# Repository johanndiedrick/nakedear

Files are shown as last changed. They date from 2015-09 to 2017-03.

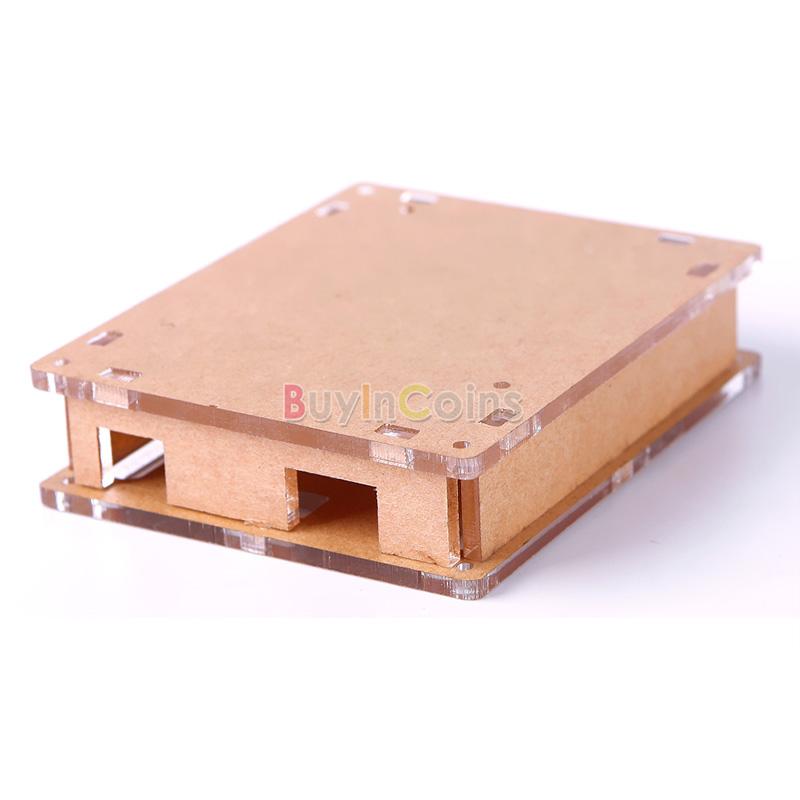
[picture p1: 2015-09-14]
materials/boxes/references/069354-1-02.jpg

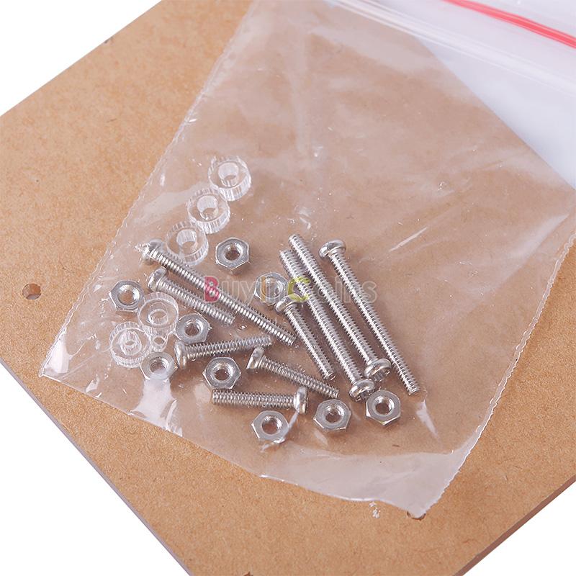
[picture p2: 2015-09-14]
materials/boxes/references/069354-1-06.jpg

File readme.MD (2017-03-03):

# Naked Ear
## Introduction to Tools and Techniques for Sound Art

### Description

This workshop is for artists and researchers wanting to become more
familiar with the potential of sound. Our focus will be on expanding our
understanding of sound in an environment. This requires a basic vocabulary
for talking about sound as a material, as well as the ability to make and
use tools for investigating and manipulating sound for creative purposes.

Our frame of reference will be Good Vibrations, a mobile listening kit that
allows "acoustic explorers" to find the lesser audible soun=
ds in their
environment. By using hand- made microphones and amplifiers, listeners can
tune into the subtle vibrations

that usually go unnoticed. The project encourages listeners to reimagine
their sonic environment by playfully exploring the world through their ears.

The workshop will introduce participants to the world of sound art, while
providing techniques for making tools for creating these experiences. This
will include

the fabrication of hand-made microphones, speakers, and amplifiers for use
in installations, performances, and scientific research. The goal of the
workshop is

to take these tools into the field and use them for artistic investigation
and public engagement.

### Content

For the first session, students will be introduced to the sound art
practice. Examples of seminal and canonical works will be presented, giving
students a taste of potential projects. From there we will move onto
describing the basic physics and properties of sound. Our introduction will
end with an explanation of how sound is received through a microphone,
amplified with an amplifier, and sent through a speaker to produce audible
sound.

The rest of the workshop will consist of building a contact microphone, a
speaker and an amplifier. From there we will take our tools out into nearby
McCarren Park and amplify found sounds.

### Outline

**Session 1**

-  Hour 1: Introductions

- Overview of sound art

- Overview of physics of sound

- Overview of how micrphone, speaker, and amplifier work

-  Hour 2: Microphone

- Contact microphone build

- https://www.youtube.com/watch?v=P8iAshJ1Pk0

- https://www.youtube.com/watch?v=yz5CM0eCGA0

-  Hour 3: Speaker

- Speaker build

-  Hour 4: Amplifier

- Amplifier build on breadboard

**Session 2**

- Hour 1:

- Amplifier build on PCB

- Hour 2:

- Placing amplifier in enclosure

- Hour 3:

- Exploring McCarren Park with listening kits

- Hour 4:

- Presentation of experiments

## Student Profile

Students do not need to have any electronic experience. Some soldering
experience is a plus but is not required. An expertise knowledge of sound
and how it works is also not required. A large part of the workshop is to
teach that to you! A strong curiosity and willingness to learn about sound
is the only basic requirement.

## What students get from your profile; software, materials to work

- One contact mic

- One speaker

- One amplifier

- One custom enclosure with custom pcb

- Reference material (excerpts from Electronic Music Handbook, David Dunn's
microphone PDF etc.)

## Pre requisites and preparation for the workshop

Things we will need in the studio for each student:

- Soldering station

- Solder

- Multimeter

- Wire

- Jumper wires

## Instructor short bio

Johann Diedrick makes installations, performances, and software that allow
people to activly participate in the production of sound. His work has been
exhibited internationally in numerous group exhibitions, conferences and
festivals, including the New Interfaces for Musical Expression (NIME)
conference in Daejeon and Seoul, Korea, the Invisible Places, Sounding
Cities conference in Viseu, Portugal, and the Dumbo Arts Festival in
Brooklyn, New York. He received his Masters in Professional Studies at the
Interactive Telecommunications Program (ITP) at Tisch School of the Arts at
New York University, focusing on sound art. During time at ITP he was a
researcher at the InterLab at the Yamaguchi Center for Arts and Media
(YCAM) in Yamaguchi, Japan. Afterwards he worked as an interactive software
developer at Qosmo in Tokyo, Japan. He is currently a software developer at
the Metropolitan Museum of Art.

## Instructor Links, website, social media

Website: http://www.johanndiedrick.com

Github: @jdiedrick

Twitter: @jdiedrick

Instagram: @johanndiedrick

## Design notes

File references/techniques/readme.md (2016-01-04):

# References

## Public Installations

[Soundaffects](http://www.creativeapplications.net/maxmsp/soundaffects-maxmsp-sound-arduino/)

[Sum of Days](http://www.moma.org/calendar/exhibitions/1151?locale=en)

##  Transmitting FM

[TRANSMITTING FM, AM, SSB, SSTV AND FSQ WITH JUST A RASPBERRY PI](http://www.rtl-sdr.com/transmitting-fm-am-ssb-sstv-and-fsq-with-just-a-raspberry-pi/)

## Acoustic Ecology

[American Society for Acoustic Ecology](http://acousticecology.us/about/)

## VLF

[VLF Radio Project](http://www.aurora-service.eu/vlf-radio-project/)

[Auroral Chorus](https://archive.org/details/AuroralChorusIiiTheMusicOfTheMagnetosphere-Disc2Of2)

## Ultrasonic (bat detectors!)

[Build a Simple Bat Detector](http://pw1.netcom.com/~t-rex/BatDetector.html)

[Bat Detector](http://www.njsas.org/projects/bat_detector/index.html)

## DIY Microphones

[Rolling Your Own Microphones](http://traktoria.org/files/sonar/Microphones_Hydrophones_Vibration-Transducers__Rolling_Your_Own__Dunn2007.pdf)

## Sine-wave speech

[Diana Deutsch' Speech to Song](http://deutsch.ucsd.edu/psychology/pages.php?i=212)

[Sine-wave speech](http://www.mrc-cbu.cam.ac.uk/people/matt-davis/sine-wave-speech/)

## Shepard Tone

[Shepard Tone](https://www.youtube.com/watch?v=BzNzgsAE4F0)

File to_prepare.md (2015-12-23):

x number of soldering stations
x number of wire strippers
Flux
x number of materials bags, enclosues, pcbs etc.
Tape
Plastic dip
Projector
Documentation - hire photographer or ask Reverse if interns will document?

longer ai/ao
acryllic
screws/longer top
4 soldering iron stations
3" screws + washers
speakers
day 1 prep
plastic bags
mini screwdriver

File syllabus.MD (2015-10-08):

# Naked Ear

**_Day 1_**

## Section One: Overview

Listening Exercise: Tristan Perich's One Bit Symphony 
Viv Corringham

Introductions

	- Name, where are you from, favorite dessert

Rules for Basic Human Decency

	- Borrow from Jer Thorp/Punk poster

Why are we all here? 

Why am I here? Because this is what I do and I wan to teach peolpe about my passion! (...)

- Introduce Good Vibrations here? I want to get their hands on it early...

Go over outline of course

- some lecture, lots of (listening) examples, mostly building and making, doing and exploring, talking and listening

### What is Sound Art?

#### Carve out definition through examples

- Sculpture

	..* _Homage to New York_, Jean Tinguely, 1960 - [MoMA Collection Page](http://www.moma.org/collection/works/81174) | [YouTube](https://www.youtube.com/watch?v=0MqsWqBX4wQ)

- Installation

	..* _Transfinite_, Ryoji Ikeda, 2011 - [Artist's website'(http://www.ryojiikeda.com/project/thetransfinite/) | [YouTube](https://www.youtube.com/watch?v=omDK2Cm2mwo)

- Environment

	..* _Times Square_, Max Neuhaus

-. Performances

	..* _Hair Hymn_, A Pure Apparatus (Xuan Ye), 2014-2015 - [Artist's website](http://a.pureapparat.us/hair-hymn/)

- Architecture

	..* Estonia forest project 

- . Something in between

	..* _viewKoma_, Tetsuya Umeda and Kanta Horio, 2006 - [YouTube](https://www.youtube.com/watch?v=42MLNXqMGzA)

#### Formal definition?

	- Look in a book

### What is sound?

Without thinking about the "art", lets examine the sound in sound art

A bit of a physics lesson...

Sound is vibration

- Vibration can be described as waves

- Show what waves are, with simple description of features (wavelength, amplititude)

Sound is vibration perceived by our ears

	- Audio-vision: earliest sense
	- Seth Horowitz, vibration being one of the first external stimuli organisms experienced

	- Explain how this translates to sound (Frequency, Intensity (vs. Loudness/Volume) )

Sound is perceived vibration by our ears within a certain range

- Show diagram of human hearing range 

- Show range of volume

Why think about sound? Why is sound important?

Sound is everywhere, literally.

The absense of sound is almost impossible

	- John Cage's Silence
	
	- Anechoic Chamber

It affects our psychology

	- Look at noise psychology studies

It affects our environment

	- Whales and noise pollution underground
	
	- Sound as indicator of biodiversity

In an arts pratice, its ripe for explorating and expression, very much overlooked and can be a powerful tool when used thoughtfully.

	- Janet Cardiff: Her Long Black Hair, 40 Part Motet, Murder of Crowes

So within all of this, what are we talking about today? What are we going to be looking at? Making?

A basic sound system with one input, one output, and a mediator in between

We're going to look at small sounds, and how we can amplify them for listening pleasure, artstic expression, and scientific investigation

Introduce Good Vibrations

Pass around and show everyone what we will be making

Explain 3 main parts, and transition into the first part we are going to focus on making

"One part is already done (headphones)! Just two parts to make"

## Section Two: Microphones

Play sound sample: Night Passages 

Explain how microphones work

In general, microphones take in vibration and translate it into a signal. How that is used depends on the application. For our purposes, we will say the microphone moves or gets excited due to vibration, converts its own vibration into an electrical signal, and recreates that signal at the other end through speakers or headphones

The microphone doesn't do all of this, but it is the input for this application.

Explain different kinds of microphones work

- Dynamic

- Condenser

- Shotgun

- Directional

- Ultrasonic: Eisuke

- Hydrophonic

- Boundary

- Binaural microphones

[David Dunn's Rolling Your Own Microphones](http://traktoria.org/files/sonar/Microphones_Hydrophones_Vibration-Transducers__Rolling_Your_Own__Dunn2007.pdf)

[Micro Listening Workshops](http://subtropics.org/micro-listening-workshops/)

We're going to look at piezo microphone, for surface vibrations. Wildly powerful, inexpensive, easy to use for a variety of applications.

Explain parts of microphone

1) Piezo

2) Audio cable

3) Standard audio jack

4) A little flair

Begin to assemble microphone

Cut wire to arms span length

Quick introduction to soldering!

- Solder pizeo

- Keep track of power vs ground

- Solder 1/4" jack, keeping in mind

- Look at Nick Collin's videos for soldering and pizeo prep references

- Plasti dip ends and wait to dry!

## Section Three: Speakers

	- Inverse of microphone

	- Explain briefly, explain that we won't be building one

## Section Four: Amplifiers

Listening exercise: VLF recordings? David Dunn's beatle recordings

Explain that while we have a microphone we need to make it a little louder for us to hear those small sounds!

So we're going to build an amplifier, a pretty basic one:

	- Diagram of circuit we are going to build

		- Ask if anyone has seen a circuit diagram before
	
	- Explain a bit what the circuit does/how it works

	- Build circuit together

		- Explain breadboard

	- Test out circuit so they know what they have built, and prepare them for tomorrow

**_Day 2_** 

Listening exercise: APA and jø - Cloudbursting

### Section Five: Assembling Part 1: Amplifier

Explain reasoning: 

	- Makes it more secure

	- Why didn't we just start with this? Makes us iterate again, for learning and practice

- Assemble PCB with parts from yesterday

### Section Six: Assembling Part 2: Enclosure

Listening exercise: TBD

- Assemble Enclosure and finish mobile listening kits!

### Section Seven: Exploring

Listening exercise: McCarren Park

- Do mobile lisening exercise in McCarren Park, prepare cards for prompts

### Section Eight: Presenting

Listening exercise: the world!

 - Come up with prompts for discussion

 - Ask for feedback for the course!

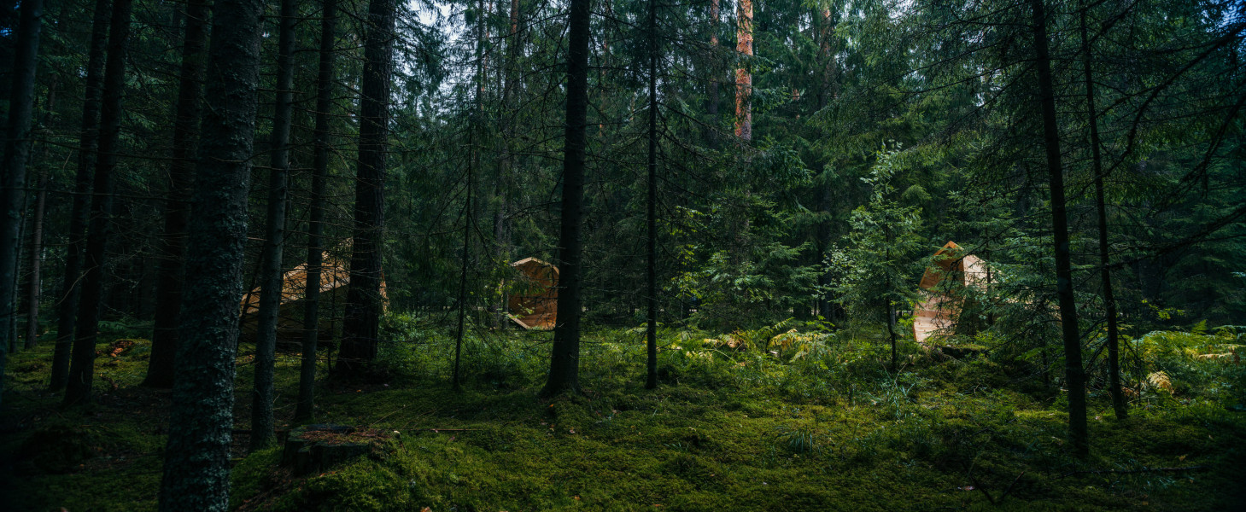
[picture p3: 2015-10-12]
presentation/img/estonia1.jpg

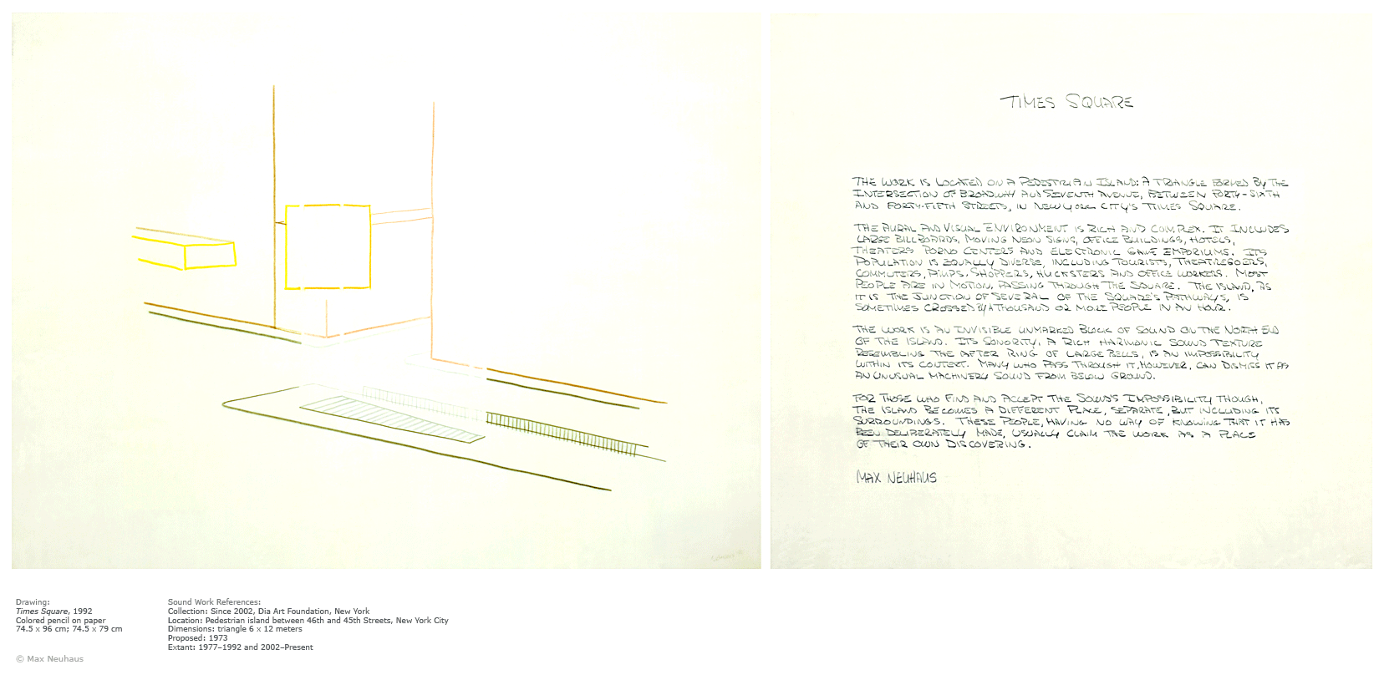
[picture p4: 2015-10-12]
presentation/img/TimesSquare.gif

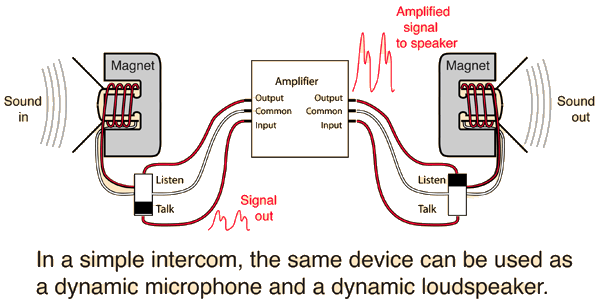
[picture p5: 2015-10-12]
presentation/img/amplifier.gif

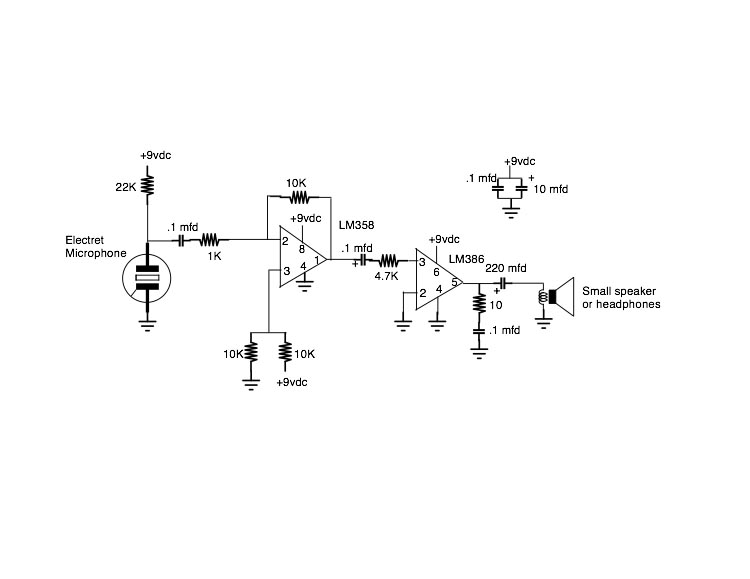
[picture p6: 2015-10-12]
presentation/img/amplifiercircuit.jpg

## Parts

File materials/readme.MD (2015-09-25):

# Materials List

## From Jameco

- [Breadboard](https://www.jameco.com/webapp/wcs/stores/servlet/ProductDisplay?productId=20601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)

- [9V Battery Clip](https://www.jameco.com/webapp/wcs/stores/servlet/ProductDisplay?productId=11280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)

- [10K Potentiometer](https://www.jameco.com/webapp/wcs/stores/servlet/ProductDisplay?productId=29082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)

- [1/4" Shaft Knob](https://www.jameco.com/webapp/wcs/stores/servlet/ProductDisplay?productId=264990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)

- [Toggle Switch](https://www.jameco.com/webapp/wcs/stores/servlet/ProductDisplay?productId=76523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)

- [220 uf Capacitor](https://www.jameco.com/webapp/wcs/stores/servlet/ProductDisplay?productId=158263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)

- [Mono Phone Jack](https://www.jameco.com/webapp/wcs/stores/servlet/ProductDisplay?productId=2100291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)

- [Stereo Phone Jack](https://www.jameco.com/webapp/wcs/stores/servlet/ProductDisplay?productId=568392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)

- [Mono Phone Plug](https://www.jameco.com/webapp/wcs/stores/servlet/ProductDisplay?productId=231160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)

- [LM386](https://www.jameco.com/webapp/wcs/stores/servlet/ProductDisplay?productId=24125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)

- [LM358](https://www.jameco.com/webapp/wcs/stores/servlet/ProductDisplay?productId=826793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)

- [Heat Shrink](https://www.jameco.com/webapp/wcs/stores/servlet/ProductDisplay?productId=2095963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)

## From Digikey

- [Piezo Elements](http://www.digikey.com/scripts/DkSearch/dksus.dll?Detail&itemSeq=180563742&uq=635787224790071919)

## From Amazon

- [Plasti Dip](http://www.amazon.com/gp/product/B00I9SK8XY/ref=ox_sc_imb_mini_detail?ie=UTF8&psc=1&smid=ATVPDKIKX0DER)

- [Pipe Cleaners](http://www.amazon.com/gp/product/B000GAZ4NC/ref=ox_sc_imb_mini_detail?ie=UTF8&psc=1&smid=ATVPDKIKX0DER)

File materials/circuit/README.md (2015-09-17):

Based on this circuit:

http://www.basicanalogcircuits.com/Session_8.html

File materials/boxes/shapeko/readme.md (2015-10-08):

http://easel.inventables.com/

notes

say materials thicker
zero z closer
holes arent big enough
needs holder for mic
slits for strap
no tabs, cut outside line
cut circles first
double depth intervals

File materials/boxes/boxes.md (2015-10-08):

http://www.ebay.com/itm/Enclosure-Transparent-Acrylic-Box-Case-for-Arduino-Uno-R3-board-R3-DIY-Useful/231496186225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

http://www.ebay.com/itm/Enclosure-Transparent-Acrylic-Box-Case-for-Arduino-Uno-R3-board-R3-/261835213419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

http://7hillsmake.org/2012/03/16/making-laser-cut-acrylic-boxesenclosures/

http://comingsoon.radioshack.com/project-enclosure-8x6x3-/2701809.html

https://www.youtube.com/watch?v=uao-sinxbBs

http://www.makercase.com/

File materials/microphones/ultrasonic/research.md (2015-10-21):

ultrasonic microphone research
http://sound.stackexchange.com/questions/2359/re-recording-ultrasonic-frequencies
http://www.wildlife-sound.org/equipment/technote/micdesigns/index.html
http://www.wildlife-sound.org/equipment/technote/micdesigns/ultrasonic.html
Knowles Acoustics FG-3329 electret condenser microphone
david dunn's manual

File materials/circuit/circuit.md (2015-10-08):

`http://www.basicanalogcircuits.com/Session_8.html`

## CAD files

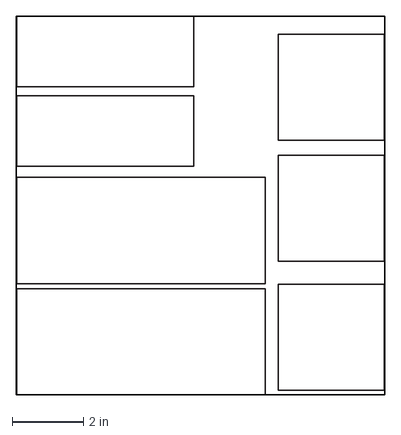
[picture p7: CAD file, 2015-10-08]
materials/boxes/designs/box_test.dxf
10.4 x 10.7 in

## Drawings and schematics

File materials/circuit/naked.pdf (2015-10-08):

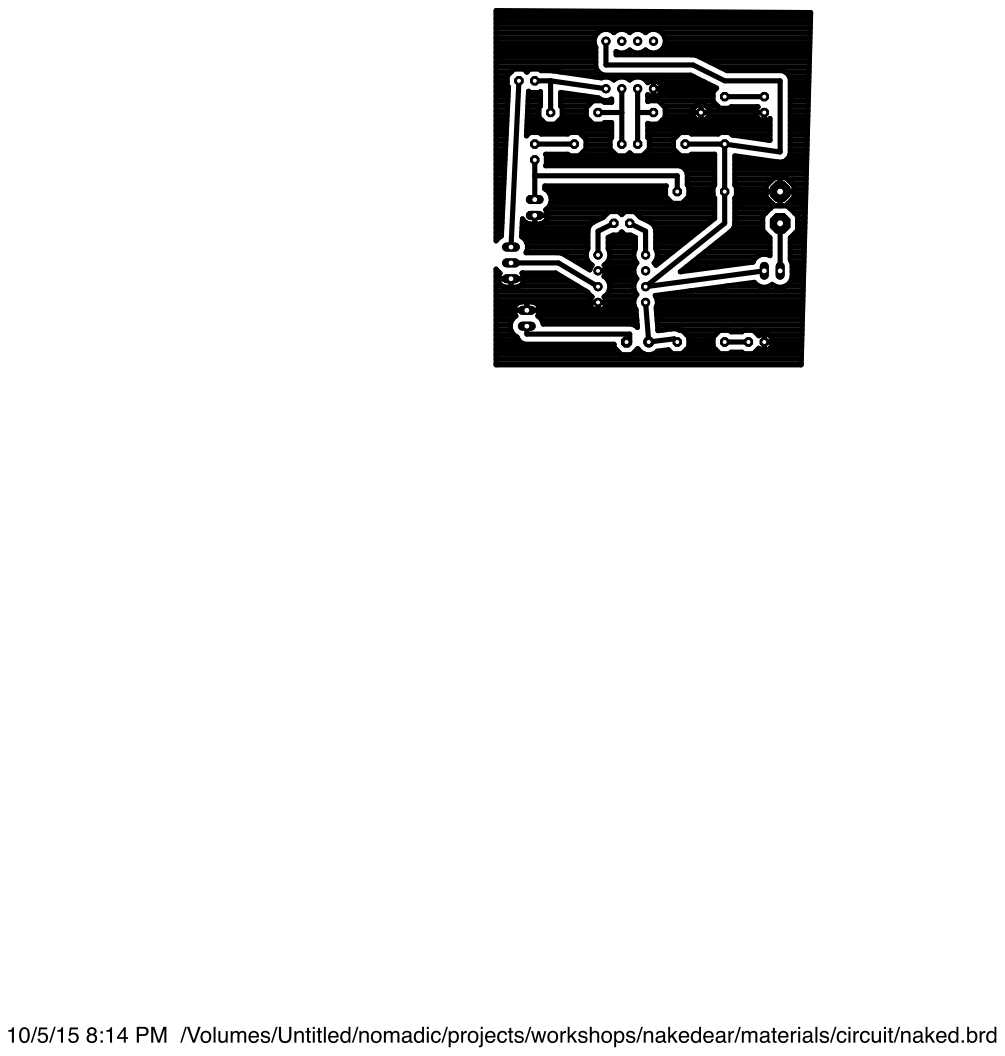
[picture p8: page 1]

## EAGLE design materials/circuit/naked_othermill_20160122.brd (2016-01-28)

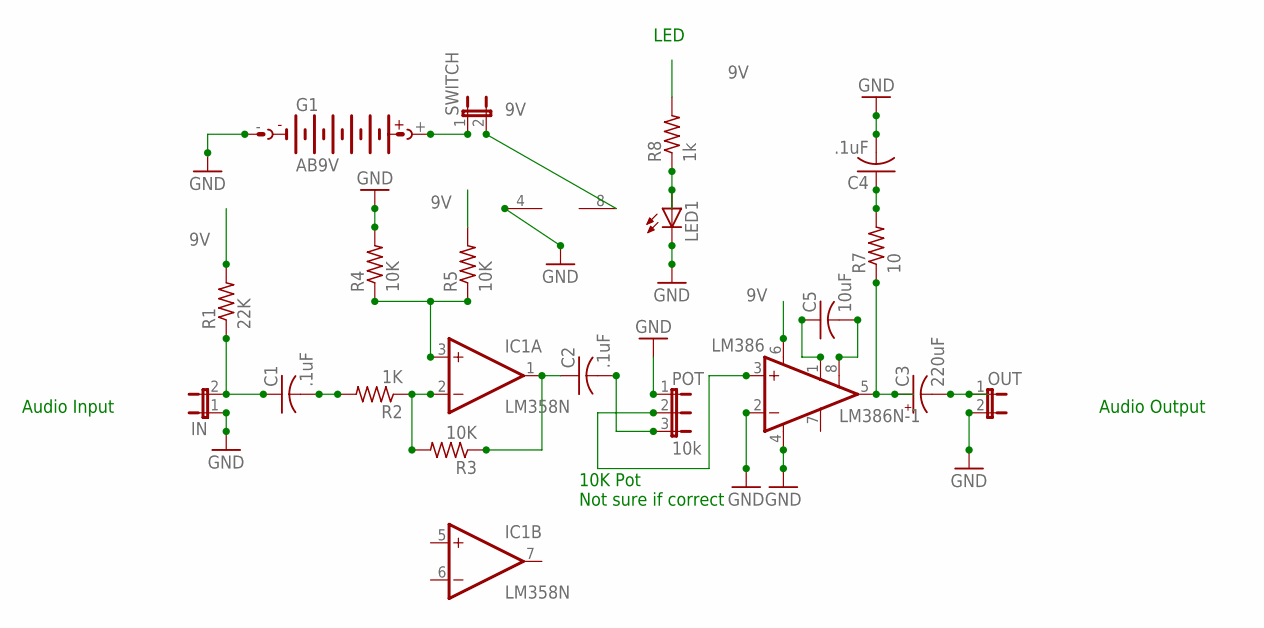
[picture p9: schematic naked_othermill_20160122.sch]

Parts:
C1, C2, C4: .1uF; C025-024X044
C3: 220uF; E3,5-8
C5: 10uF; C025-024X044
G1: AB9V
IC1: LM358N; DIL08
IN: JP1E; JP1
LED1: LED5MM
LM386: LM386N-1; DIL08
OUT: JP1E; JP1
POT: 10k; JP2
R1: 22K; 0204/7
R2: 1K; 0204/7
R3, R4, R5: 10K; 0204/7
R7: 10; 0204/7
R8: 1k; 0204/7
SWITCH: JP1E; JP1

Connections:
9V: IC1.8 (V+), LM386.6 (VS), R1.2, R5.2, R8.2, SWITCH.2
GND: C4.2, G1.-, IC1.4 (V-), IN.1, LED1.K (C), LM386.2 (-IN), LM386.4 (GND), OUT.2, POT.1, R4.2
unnamed: G1.+, SWITCH.1
unnamed: C1.1, IN.2, R1.1
unnamed: C1.2, R2.2
unnamed: IC1.2 (-IN), R2.1, R3.2
unnamed: C5.1, LM386.1 (GAIN)
unnamed: IC1.3 (+IN), R4.1, R5.1
unnamed: C2.1, IC1.1 (OUT), R3.1
unnamed: C2.2, POT.3
unnamed: LM386.3 (+IN), POT.2
unnamed: C3.+, LM386.5 (OUT), R7.1
unnamed: C3.-, OUT.1
unnamed: LED1.A, R8.1
unnamed: C4.1, R7.2
unnamed: C5.2, LM386.8 (GAIN)

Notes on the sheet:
Audio Input
Audio Output
LED
10K Pot Not sure if correct

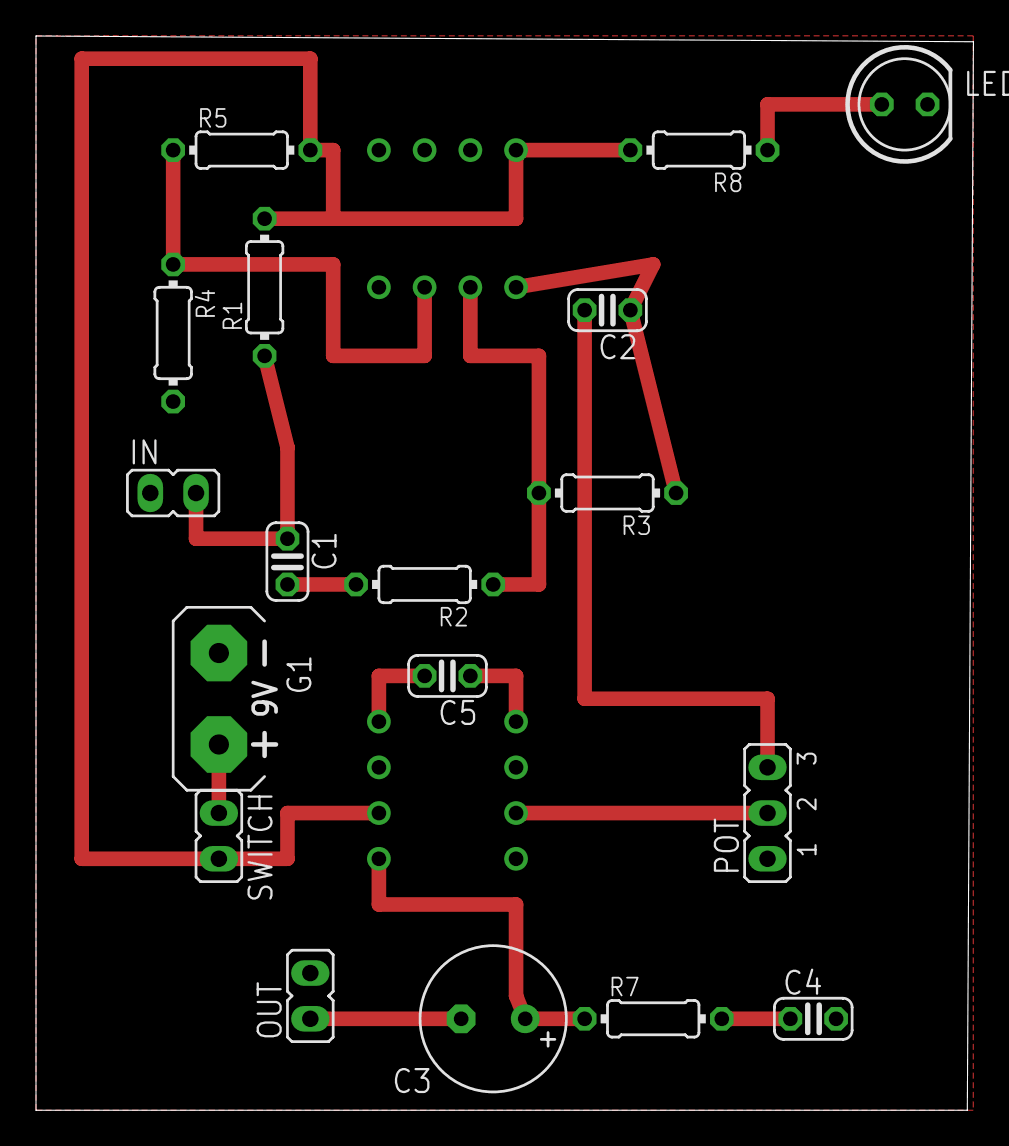
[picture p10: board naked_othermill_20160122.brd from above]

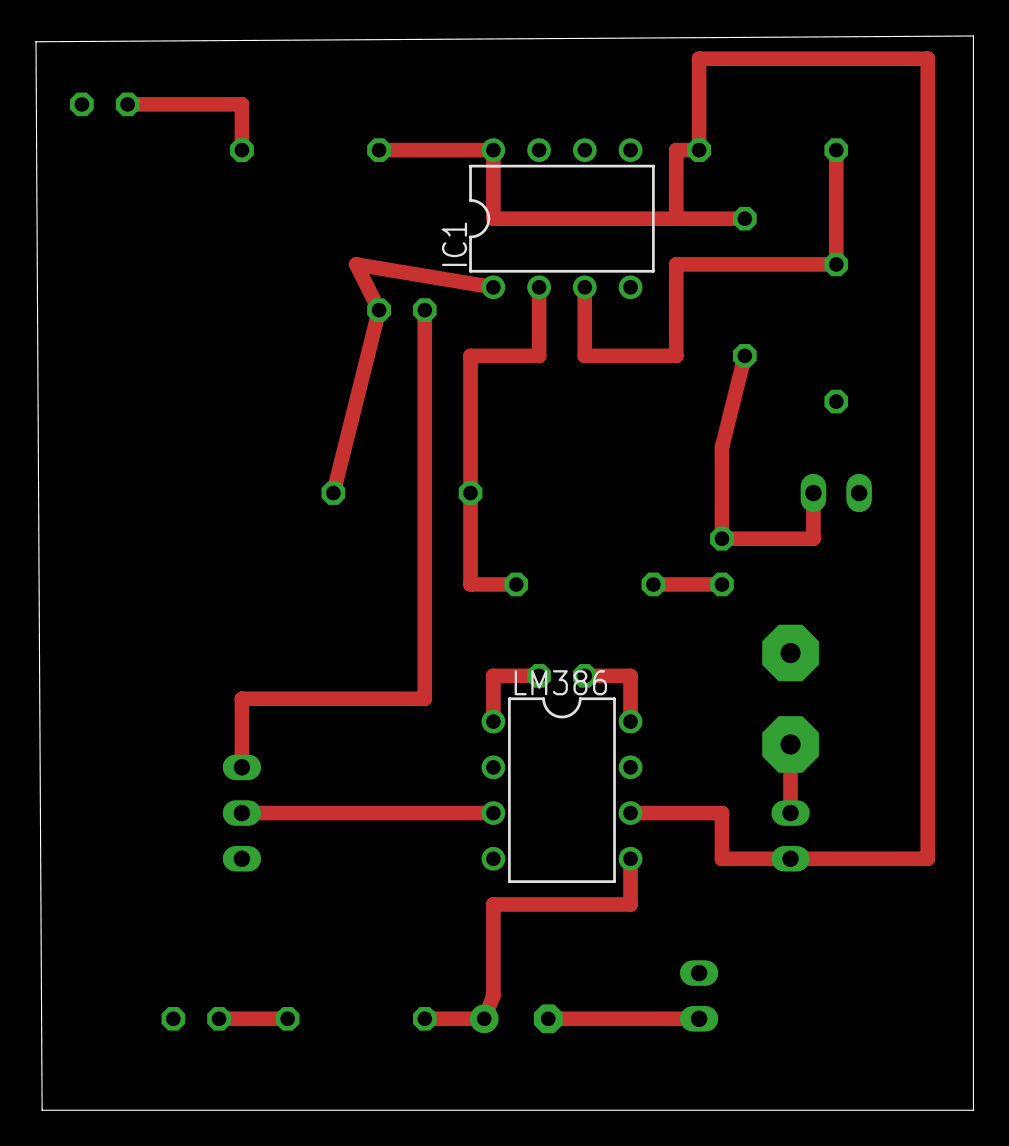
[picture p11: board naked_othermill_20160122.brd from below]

Board: 2 copper layers, 52.1 x 59.7 mm, 20 parts (2 on the bottom side), 16 nets.

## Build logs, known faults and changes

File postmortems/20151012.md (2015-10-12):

-Better soldering irons
-More solder
-Bigger space in PCBs

-Split workshops into two: 

1) One with lecture, contact mic build, prebuilt listening kits, tour, how to record/special questions/topics

2) One intermediate with how circuit works building amps on pcb board

Day 1: 

Went well, need more time to set up chairs, projectors, tables. Lecture went well

Day 2: 

Not so good. Soldering custom printed PCBs a terrible decision. No one finished.

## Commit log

2015-09-16 added circuit and breadboard design
    [naked.brd, naked.sch]
2015-09-17 deleted brd, updated board w led and pot
    [naked.brd, naked.sch]
2015-09-17 added readme for circuit
2015-09-25 updates to materials and syllabus
2015-09-25 updated materials
2015-10-08 added box designs, circuit, presentation etc
    [box_test.dxf, naked.brd, naked.sch]
2015-12-23 updates with othermill and references
    [naked.brd, naked_othermill.brd, naked_othermill.sch]
2016-01-24 added updated circut designs, updated some online references
    [naked_othermill_2.brd, naked_othermill_2.sch, naked_othermill_20160122.brd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]
2016-01-28 updated online resources
    [naked_othermill_20160122.brd]
